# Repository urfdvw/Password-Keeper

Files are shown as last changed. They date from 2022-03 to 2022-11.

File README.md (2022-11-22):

[中文文档](READMEZH.md)

# Password Keeper
A handy DIY off-line password management device.

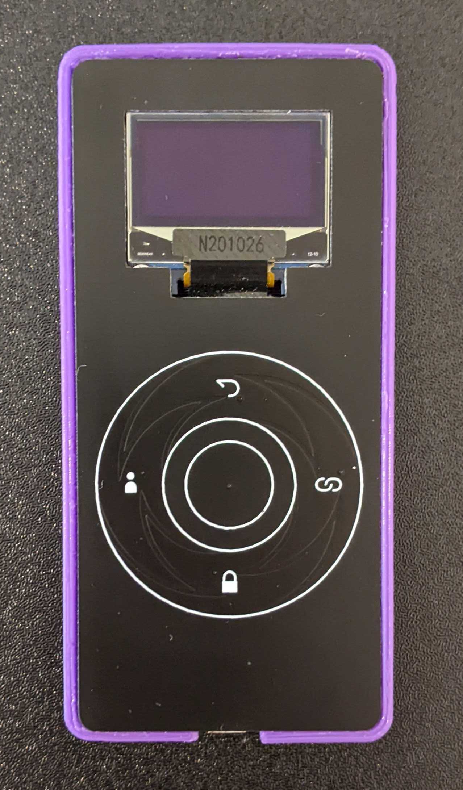
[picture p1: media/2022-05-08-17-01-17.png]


## Why
This DIY project is a USB password management device for people who
- hate auto-saving passwords on browsers
- use public computers or changes devices all the time
- are forced to set a different "strong" password every month (me)
- have a lot of super-long passwords, such as Github keys and SSH keys
- just want to try out another CircuitPython Project. 

***Disclaimer**:
This project only contains an off-line microcontroller code and a static pure front-end page.
Your password data will not be stored or sent via the internet due to the effect of this project.
This project focus on user experiences.
In other words,
using this project cannot improve the security of your passwords.
The author of this project is not responsible for any possible loss or leak of your passwords or accounts.
Using the code in this repository means you accept this disclaimer, fully understand the code's functionality,
and will take all risks.*

## Based on
Hardware and modules
- Pi Pico
- I2C SSD1306 OLED screen

Languages and libraries
- CircuitPython 7.0.0
    - displayio
    - usb_hid
    - touchio
- JavaScript
    - Chrome File API
    - Ace Editor

Techniques
- Finite state machines
- Vigenère cipher

## Additional resource
- For circuit and PCB, please check: https://oshwlab.com/urfdvw/password-keeper_copy_copy

## How to make
- Make the PCB and solder the components on to the PCB board
- Install CircuitPython on the Pi Pico
- Copy the code to the CIRCUITPY drive
- 3D print the case according to the case, and glue it to the back

### Example data
In newly made keeper device, the default data file `items.csv` contains some example data.
    - master password is `0` (one digit string zero),
    - password of the `i`th item is `password{i}`, where `{i}` is a placeholder.

## How to use

### Update data
- Connect your password keeper to your computer
- Open [Password Keeper Manager](https://urfdvw.github.io/Password-Keeper/) in browser
- Type in your master password
    - If it is the first time you use it, the default master password is `0` (one digit string zero),
- Click on [Open] and open the `items.csv` file on your `CIRCUITPY` drive
    - If your master password is wrong, the `Deciphered Text` is going to show wrong passwords
- Make changes to your account information in the `Deciphered Text` area, following csv formate
- If you need a new, you can click on [Random Password] button to generate a strong password.
- Click on [Save] to save changes
- ***It is suggested that you keep a backup of `items.csv` by [Save As], and store that ciphered data file in a safe place*** 

### Log in using the password keeper
- Connect the Password Keeper with the computer or phone with proper USB wire
- Type in Master password on your password keeper
    - rotate to change characters
    - right to add a new character
    - left to delete the last character
    - center to confirm
- Find out your account in the list
    - rotate to scroll
    - center to select
    - up to go back
- In the account
    - right to type in URL
    - left to type in user name
    - down to type in password
    - up to go back

### Change Master Password
- With current Master Password, Open your ciphered data file `items.csv` in the [Password Keeper Manager](https://urfdvw.github.io/Password-Keeper/)
- Make sure you are seeing the correct passwords in the `Deciphered Text` area
- Change the Master Password in the manager
- Click on [Save] to save modifications

## How to extend
Software extension suggestion
- You can make your own mini App and list it in the menu
    - Please see [Developer Memo](./memo.md) for details

Hardware extension suggestions
- You can use the touch ring on any of your own DIY projects
    - The [driver code](./code/driver.py) can be used directly
    - Check out the [Python Script](https://colab.research.google.com/github/urfdvw/Password-Keeper/blob/main/wheel%20design/draw%20wheel%20svg.ipynb) that generates the wheel pattern that can be imported to your PCB design.
---
# Happy Coding

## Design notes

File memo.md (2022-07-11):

# Developer Memo
Here, I note logic that is not obvious by code.

This project is not only to build a working device for password management,
it also aims to provide a framework for
"Sort of complex" devices with
similar hardware that runs
multiple mini-apps,
and multiple background procedures.

# class dependency tree
- `App` (ABC): Apps with OLED UI
    - `BounceBall`: A game app
    - `Item`: App for typing password
    - `Menu` (ABC): Apps with list of text as menu
        - `Mainmenu`: App for main menu
        - `AccountList`: App for list accounts
- `Background_app` (ABC): Apps without UI
    - `FpsControl`
    - `FpsMonitor`

# File structure
All board specifications are in code.py.
Peripheral drivers are in driver.py.
Time-related tools are defined in timetrigger.py
Apps with UI are in Aplication.py
Background processes are in backgrounf.py

# code.py structure
- hardware and then software object instanciation and initialization should be here
    - class definitions should be in other modules
    - out put first and input after
        - this is for displaying debug info when not using USB
            - Should try BLE work flow later
- while true main loop at the end for managing the life cycle of the apps.

# Sound
- all sounds are just a brief beep (one frame) unless special usage
    - tic-toc is used to avoid continuous sound
- sound is controlled by `self.freq`
    - it is going to control the buzzer for one frame
- press sound is only for the indication (1000)
    - so, in UI input
- release sound is when the action is taken (1200)
    - so, in logic
- as sound is so different in every app
    - here, we sacrifice the reusability
    - and let each app decide what sound they want

# Life cycle of application
The life cycle only contains three parts: receive, update, and display.
This is designed for simple logic instead of complex procedures.
```
0 (device power on)
1 __init__
2 (wait)
3 reveive()
4 display()
5 (repeat frames)
6 | update()
7 | display()
8 update() (with exit signal)
9 (wait)
10 back to step 3 when called again
```
- receive is viewed as the entry point of the app, usually
    - contains an enter sound
    - contains state initialization
- display is considered following an update step or a receive step
    - Exception: update with exit operation does not have display step following

# Message transmission between apps
Messages are transferred in two ways:
- direct message
- broadcasting

A direct message is used between two consecutive apps.
This should be used as much as possible.
It is convenient for apps to help each other to finish a task in a relay.

Broadcasting should only be used for states or important global messages.
It can only be overwritten instead of removed.
Use it wisely.

shift signal should and should only be used for app shifting signal.
usually
- 0 means no action
- -1 means back
- 1 and above means other apps.

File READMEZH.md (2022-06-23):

# 密码账簿
一种 DIY 离线密码管理器设备



## 动机
这个 DIY 项目的核心是一个密码管理设备。
它适合以下人群：
- 不喜欢在浏览器里保存密码的人
- 经常要使用公共电脑或者经常换电脑或重装系统的人
- 由于工作原因，每隔一段时间就必须要换密码的人。
- 密码超级长，或者需要使用长密钥（比如 github key 或者 SSH key）的人。
- 入门 CircuitPython 开发或者，纯心想折腾一下的人。

***免责声明**：
本项目仅包含离线的单片机代码和静态前端网页，并没有任何后端服务，
所以本项目并不会在网络上存储或转发您的密码数据。
这个项目把使用体验放在第一位，
换句话说使用这个项目并不能让你的密码更安全。
如果您因为使用本项目中的代码而导致重要的账户或数据丢失或者泄露，
本项目的作者不承担责任。
如果您使用了本项目中的代码，
就等同于认可了本声明，
并全面了解代码的实际运作方式，
且意承担全部风险。*

## 基于的技术
硬件和硬件模块
- Pi Pico
- I2C SSD1306 OLED 显示器

语言和库
- CircuitPython 7.0.0
    - displayio
    - usb_hid
    - touchio
- JavaScript
    - Chrome File API
    - Ace Editor

技术
- 有限状态机
- 维吉尼亚加密

## 其他资源
- 请在以下网址查看电路设计和PCB: https://oshwlab.com/urfdvw/password-keeper_copy_copy

## 如何制作
- PCB 打样后并焊接元件。
- 在 Pi Pico 上安装 CircuitPython。
- 将本 repository 中的代码拷贝到 CIRCUITPY 磁盘中。
- 将本 repository 中的后盖 3D 模型打印出来，并用热熔胶粘接到 PCB 后面。

### 数据样例
在新制作的账簿中包含一个样例数据文件 `items.csv`。
    - 其主密钥为 `0` （一个包含数字“零”的字符串）。
    - 第 `i` 个账户的密码是 `password{i}`，其中 `{i}` 是占位符。

## 如何使用

### 更新密码数据
- 用 USB 线将密码账簿设备链接到电脑
- 在浏览器中打开网页 [Password Keeper Manager](https://urfdvw.github.io/Password-Keeper/)
- 在 `master password` 处输入主密钥
    - 如果您是第一次使用，默认的主密钥为 `0` （一个包含数字“零”的字符串）。
- 点击界面中的 [Open] 按键，选择 `CIRCUITPY` 磁盘中的 `items.csv` 文件
    - 密码数据会显示在 `Deciphered Text` 区域
    - 如果主密钥输入错误， 那么显示出来的数据会是错误的数据。
- 在 `Deciphered Text` 区域增加或者修改密码数据。
- 如果您需要，也可以点击 [Random Password] 按键，这样会在光标处输入一段纯随机的强密码。
- 点击界面中的 [Save] 按键，所有的修改会被保存。
- ***注意：强烈建议您将 `items.csv` 备份在安全的地方。*** 

### 如何使用**密码账簿**设备
- 用 USB 线将密码账簿设备链接到电脑
- 在密码账簿设备上输入主密钥
    - 旋转转盘切换字母
    - 右键输入新的字符
    - 左键删除最后一个字符
    - 中键确认密钥
- 在列表中找到需要的账户名
    - 旋转转盘以寻找账户
    - 中键进入账户
    - 上键回到密钥输入界面
- 在账户界面下
    - 右键输入网址
    - 左键输入用户名
    - 下键输入密码
    - 上键返回到账户列表

### 修改主密钥
- 在 [Password Keeper Manager](https://urfdvw.github.io/Password-Keeper/) 中，用原有的主密钥打开`items.csv`。
- 请确认 `Deciphered Text` 区域中的密码是正确的。
- 修改 `master password` 区域中的主密码
- 点击界面中的 [Save] 以保存修改

## 如何扩展本项目
软件扩展
- 您可以设计自己的小程序，并放在菜单中
    - 关于小程序的设计细节请参考[设计备忘录](./memo.md)

硬件扩展
- 您可以将转盘的设计用于其他类似的项目中
    - 您可以直接使用本项目的[驱动代码](./code/driver.py)

---
# Happy Coding

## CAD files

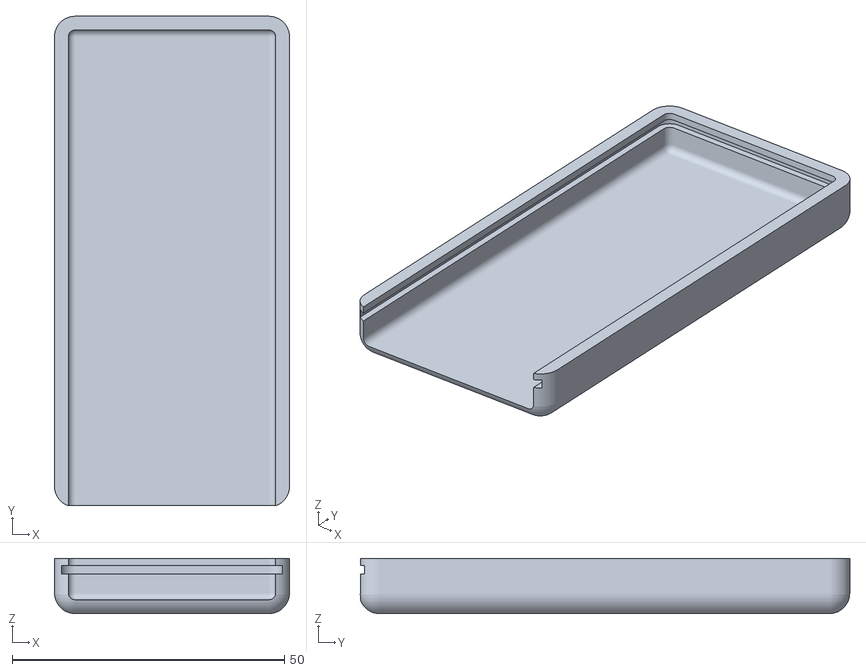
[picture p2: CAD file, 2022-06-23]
3D model/password keeper pi pico slide.stl
43.2 x 90.0 x 10.2

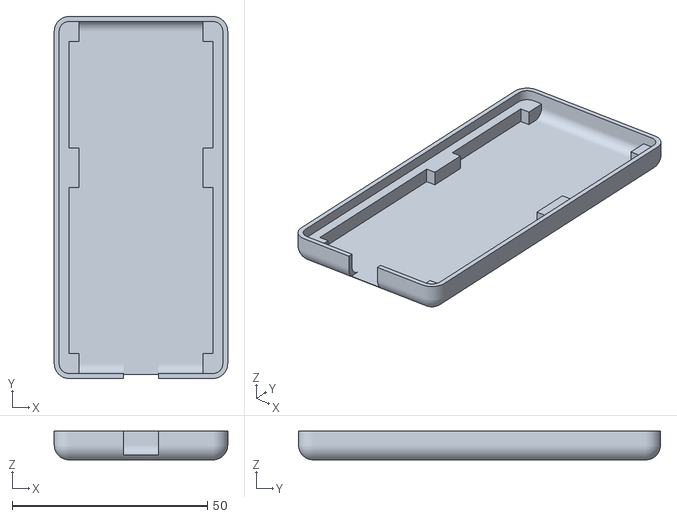
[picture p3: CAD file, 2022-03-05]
3D model/Password keeper Pico case.stl
44.4 x 92.7 x 7.36

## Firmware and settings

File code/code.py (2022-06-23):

"""
This script is the entry point of all scripts.
Please check the .url files for more help

Github: https://github.com/urfdvw/Password-Keeper/

Platform: Password Keeper
CircuitPython: 7

Author: River Wang
Contact: urfdvw@gmail.com
License: GPL3
Date updated: 2022/06/21 (YYYY/MM/DD)
"""
import board

#%% buzzer
from driver import Buzzer
buzzer = Buzzer(board.GP0)

#%% clickwheel
from driver import Ring, Button
center = Button(board.GP9)
ring = Ring(
    [
        board.GP10, # left
        board.GP12, # up
        board.GP27, # down
        board.GP21, # right
    ],
    center,
)

#%% find the range of raw_value for ring pad.
# run this code if you are testing a new PCB design
if False:
    from time import monotonic, sleep
    tic = monotonic()
    ring_max = [0] * 4
    ring_min = [100000] * 4
    while monotonic() - tic < 5:
        # run the test for 5s
        # in the mean time, slide on the ring for multiple cycles.
        for i in range(4):
            value = ring.ring[i].raw_value
            ring_max[i] = max(ring_max[i], value)
            ring_min[i] = min(ring_min[i], value)
            # print(ring_max, ring_min)
            sleep(0.1)
    print(ring_max, ',', ring_min)
    # cancel running the original script
    import sys
    sys.exit()

#%% use pre measured max and min
ring.max, ring.min = [2322, 2651, 2147, 2009], [794, 807, 941, 785]

#%% define screen
import busio
import displayio
import adafruit_displayio_ssd1306

displayio.release_displays()
oled_reset = None
i2c = busio.I2C(board.GP17, board.GP16, frequency=int(1e6))
display_bus = displayio.I2CDisplay(i2c, device_address=0x3C, reset=oled_reset)
WIDTH = 128
HEIGHT = 64
display = adafruit_displayio_ssd1306.SSD1306(display_bus, width=WIDTH, height=HEIGHT, rotation=0)

#%% USB HID
import usb_hid
from adafruit_hid.keyboard import Keyboard
from adafruit_hid.mouse import Mouse

while True:
    try:
        # Keep trying connect to USB untill success
        # This useful for computer log in after boot.
        mouse = Mouse(usb_hid.devices)
        keyboard = Keyboard(usb_hid.devices)
        break
    except:
        print('\n' * 10 + 'USB not ready\nPlease Wait')

#%% Background apps
from background import FpsControl, FpsMonitor, NumLocker, MouseJitter

frame_app = FpsControl(fps=30)
fpsMonitor_app = FpsMonitor(period=10, fps_app=frame_app)
num_app = NumLocker(keyboard=keyboard)
mouse_app = MouseJitter(mouse=mouse, period=60)

#%% apps
from application import BounceBall, MainMenu, Password, AccountList, Item, ClickWheelTest
app_ball = BounceBall()
app_menu = MainMenu([
    'password keeper',
    'bounce ball',
])
app_pass = Password()
app_accounts = AccountList()
app_item = Item(keyboard)
app_test = ClickWheelTest()

app = app_pass # app to start from

#%% Main logic
print('init done')
memo = {}
while True:
    # Background procedures
    fpsMonitor_app()
    mouse_app()
    num_app()  # For Windows Only

    # FPS control
    if not frame_app():
        continue

    # logic
    shift, message, broadcast = app.update(ring.get())
    memo.update(broadcast)
    if shift:
        if id(app) == id(app_menu):
            if shift == 1:
                app = app_pass
            elif shift == 2:
                app = app_ball
        elif id(app) == id(app_pass):
            if shift == -1:
                app = app_menu
            if shift == 1:
                app = app_accounts
        elif id(app) == id(app_accounts):
            if shift == -1:
                app = app_pass
            if shift == 1:
                app = app_item
        elif id(app) == id(app_item):
            if shift == -1:
                app = app_accounts
        elif id(app) == id(app_ball):
            if shift == -1:
                app = app_menu
        app.receive(message, memo)

    # display changes
    app.display(display, buzzer)

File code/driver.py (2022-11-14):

"""
This script contains driver classes for perferials, include
- buzzer
- the PCB touch clickwheel (sometimes called the `ring` in the code)
"""
#%% buzzer
import pwmio

# define buzzer
class Buzzer:
    """
    Driver class of the buzzer
    """
    def __init__(self, pin):
        self.buzzer = pwmio.PWMOut(pin, variable_frequency=True)
        self.buzzer.duty_cycle = 0
    def beep(self, freq):
        """
        Turn the buzzer on at a certain sound wave frequency
        freq=0 to turn off
        """
        if freq == 0:
            self.buzzer.duty_cycle = 0
            return
        else:
            self.buzzer.frequency = freq
            self.buzzer.duty_cycle = 32768
            return

#%% clickwheel
import touchio
from math import sqrt, atan2, pi, exp, sin
import time
from timetrigger import Timer

# Relay to filter out shakes
class ThetaFilter:
    def __init__(self):
        self.thr = pi / 30
        self.remain = 0
    # on theta
    def __call__(self, x):
        # return (1 / (exp(-x) +1) - 0.5) * 2 * abs(x) * 2.5 + 0.5 * x
        self.remain += x
        if self.remain > self.thr:
            y = self.remain - self.thr
        elif self.remain < -self.thr:
            y = self.remain + self.thr
        else:
            self.remain *= 0.95
            y = 0
        self.remain = self.remain - y
        return y
theta_filter = ThetaFilter()

# # uncomment and ctrl enter for plot and testing
# print('startplot:', 'y1', 'y2')
# y1 = 0
# y2 = 0
# for i in range(0, 70):
#     t = i / 100
#     x = sin(t * 10)
#     y1 += x
#     y2 += theta_filter(x)
#     print(y1, y2)

#%%
            

def theta_diff(a, b):
    c = a - b
    if c >= pi:
        c -= 2 * pi
    if c < - pi:
        c += 2 * pi
    return c

# define button
class Button:
    """
    Driver class of a single button
    """
    def __init__(self, pin):
        self.touch = touchio.TouchIn(pin)
        self.need_init = True
        self.current = False
        self.last = False
        self.en = True

    def get(self):
        # init on the first check
        if self.need_init:
            time.sleep(0.1)
            self.touch.threshold = self.touch.raw_value + 100
            self.need_init = False
        # compute output
        self.current = self.touch.value
        out = 0
        if self.current and (not self.last):
            out = 1 # press edge
        elif (not self.current) and self.last:
            if not self.en:
                self.en = True
            else:
                out = -1 # release edge
        elif self.current and self.last:
            out = 2 # hold

        self.last = self.current
        if self.en:
            return out
        else:
            return 0

# define ring
class Ring:
    """
    Driver class of the touch clickwheel
    """
    def __init__(self, pins, center, N=8):
        # center button
        self.center = center
        # ring pins
        self.ring = []
        for i in range(4):
            time.sleep(0.05)
            self.ring.append(touchio.TouchIn(pins[i]))
        # ring value range init
        self.min = []
        self.max = []
        for i in range(4):
            time.sleep(0.05)
            self.min.append(self.ring[-1].raw_value)
            self.max.append(self.min[-1] + 120)
        # constants
        self.alter_x = [-1, 0, 0, 1]
        self.alter_y = [0, 1, -1, 0]
        filtering_N = 2
        self.filtering_alpha = 1 / filtering_N
        self.dial_N = N
        # states
        self.pos_x = 0
        self.pos_y = 0
        self.r = 0
        self.theta = 0
        self.theta_last = 0
        self.theta_d = 0
        self.theta_residual = 0
        self.touch = False
        self.touch_last = False
        self.dial_changed = False
        # timer
        self.hold_timer = Timer()

    def get(self):
        # read sensor
        center_now = self.center.get()
        ring_now = [r.raw_value for r in self.ring]

        # conver sensor to weights
        w = [
            (ring_now[i] - self.min[i]) / (self.max[i] - self.min[i])
            for i in range(4)
        ]

        # computer vector sum
        pos_x = sum([w[i] * self.alter_x[i] for i in range(4)])
        pos_y = sum([w[i] * self.alter_y[i] for i in range(4)])

        # 1st-order low pass filter
        self.pos_x = pos_x * self.filtering_alpha \
            + self.pos_x * (1 - self.filtering_alpha)
        self.pos_y = pos_y * self.filtering_alpha \
            + self.pos_y * (1 - self.filtering_alpha)

        # covert xy to polar
        self.r = sqrt(self.pos_x ** 2 + self.pos_y ** 2)
        self.theta = atan2(self.pos_y, self.pos_x)

        # covert r to touch
        self.touch = self.r > 0.3

        # init outputs
        dial = 0

        buttons = {
            'left': 0,
            'right': 0,
            'up': 0,
            'down': 0,
            'center': 0,
            'ring': 0,
        }

        # touch conditions
        if self.touch and not self.touch_last: # ring touch edge
            buttons['ring'] = 1
            if self.pos_x > abs(self.pos_y): # right
                buttons['right'] = 1
            if self.pos_x < -abs(self.pos_y): # left
                buttons['left'] = 1
            if self.pos_y > abs(self.pos_x): # up
                buttons['up'] = 1
            if self.pos_y < -abs(self.pos_x): # down
                buttons['down'] = 1
            # init dial states
            self.theta_residual = 0
            self.theta_d = 0
            self.theta_last = self.theta
            self.dial_changed = False
        elif self.touch and self.touch_last: # ring hold
            buttons['ring'] = 2
            self.theta_d = theta_filter(theta_diff(self.theta, self.theta_last))
            self.theta_residual += self.theta_d
            while self.theta_residual > pi / self.dial_N:
                self.theta_residual -= 2 * pi / self.dial_N
                dial += 1
            while self.theta_residual < -pi / self.dial_N:
                self.theta_residual += 2 * pi / self.dial_N
                dial -= 1
            if dial:
                self.dial_changed = True
        elif not self.touch and self.touch_last: # ring release edge
            buttons['ring'] = -1
            if not self.dial_changed:
                if self.pos_x > abs(self.pos_y): # right
                    buttons['right'] = -1
                if self.pos_x < -abs(self.pos_y): # left
                    buttons['left'] = -1
                if self.pos_y > abs(self.pos_x): # up
                    buttons['up'] = -1
                if self.pos_y < -abs(self.pos_x): # down
                    buttons['down'] = -1
        else: # ring idle
            # center button only works when ring is not touched
            buttons['center'] = center_now

        # hold detect
        buttons_hold = {
            'left': 0,
            'right': 0,
            'up': 0,
            'down': 0,
            'center': 0,
        }
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

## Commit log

2022-01-08 first working prototype
2022-01-08 input for master password
    [items.csv]
2022-01-15 moved data
    [items.csv]
2022-03-05 change license
    [Password keeper Pico case.stl]
2022-03-06 中文 文档
2022-05-08 52840 feather
    [items.csv]
2022-05-08 bug fix
    [items.csv]
2022-06-23 Major Version 1
    Fixed so many issues
    [password keeper pi pico slide.stl]
2022-07-11 optimize battery range measuring
2022-11-22 Refine wheel description
